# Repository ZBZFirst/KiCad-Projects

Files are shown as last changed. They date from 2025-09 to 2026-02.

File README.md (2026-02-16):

# ESP32 Controller

---

## Reference Images

### PCB Layout

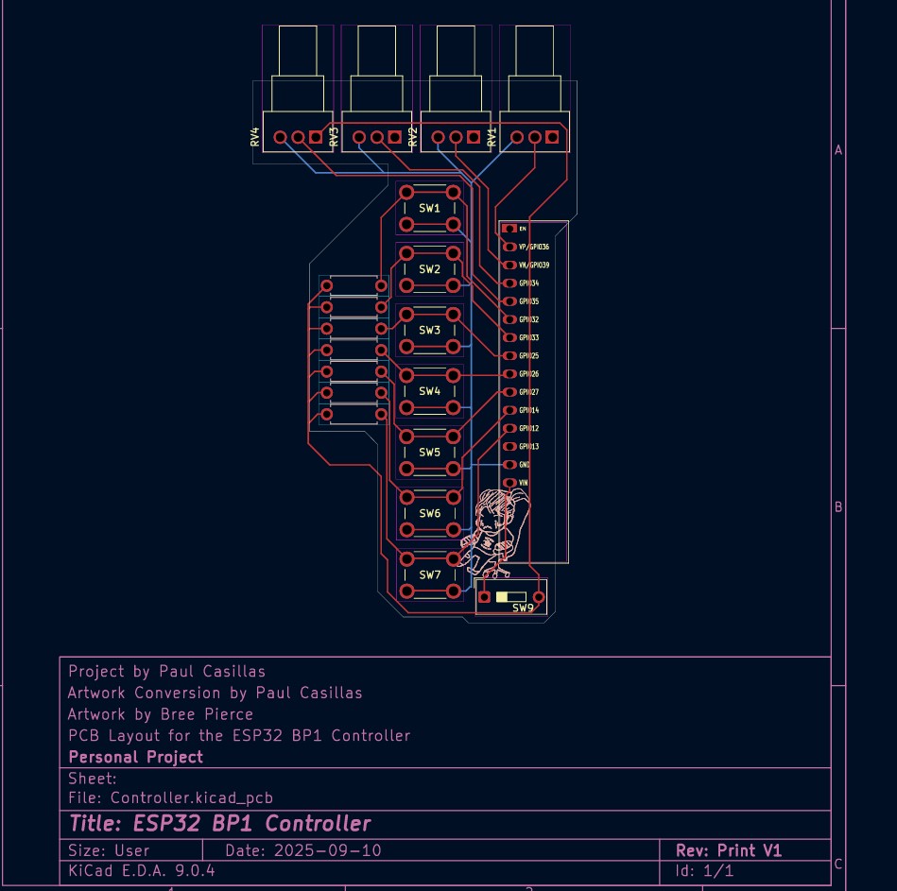
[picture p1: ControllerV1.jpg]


### Attachment

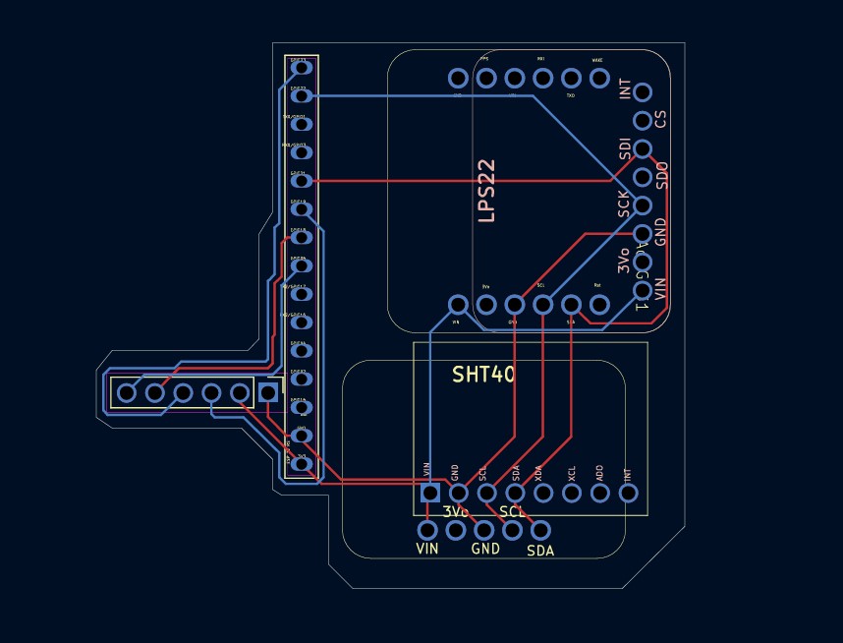
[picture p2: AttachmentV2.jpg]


### Finished Build

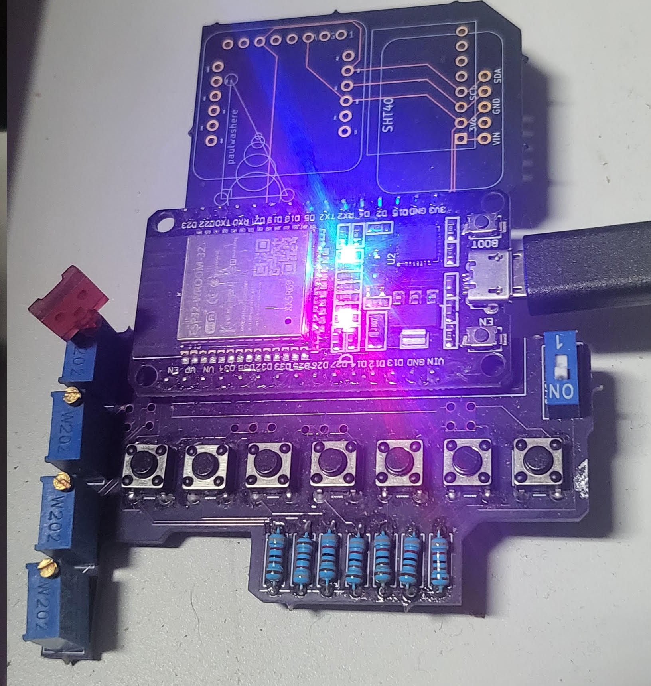
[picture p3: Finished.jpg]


---

Custom ESP32 BLE HID controller + matching PCB design.

This project combines:

- ESP32 firmware (BLE composite keyboard + mouse)
- KiCad PCB layout for a dedicated 7-button controller
- Multi-mode input system for productivity + automation

Designed as a personal hardware controller that behaves like a wireless keyboard/mouse macro pad.

---

## Features

- BLE composite HID device (keyboard + mouse)
- 7 physical buttons
- Mode switching system
- Auto-click / auto-key spam mode
- Windows quick-launch macros
- Non-blocking firmware architecture
- Visual LED status patterns
- Custom PCB layout (KiCad)

---

## Hardware

### Board

ESP32-based custom PCB with:

- 7 tactile switches
- Onboard LED status indicator
- ESP32 dev module header
- Dedicated GPIO routing per button

KiCad layout included in repository.

File:

```
hardware/Controller.kicad_pcb
```

This board is designed specifically to run the included firmware.

---

## Firmware Behavior

The controller has **3 operating groups**.

Button 6 cycles groups.  
Button 7 forces disconnect (reboot).

---

### Group 1 — Default Productivity

| Button | Action |
|---|---|
| B1 | Ctrl + C |
| B2 | Ctrl + V |
| B3 | Ctrl + X |
| B4 | Ctrl + Z |
| B5 | 8-second mouse movement run |

LED: solid ON when connected

---

### Group 2 — Work Launch Macros

| Button | Action |
|---|---|
| B1 | Windows search → cmd → ssh CB37 |
| B2 | Launch Edge |
| B3 | Launch Super |
| B4 | Launch Arduino |
| B5 | Launch Bluetooth |

LED: 2 blink pattern

---

### Group 3 — Auto Mode

Toggle behaviors:

| Button | Mode |
|---|---|
| B1 | Auto left click |
| B2 | Auto right click |
| B3 | Auto middle click |
| B4 | Spam key “E” |
| B5 | Spam key “F” |

Press the same button again to stop.

LED: 3 blink pattern

---

## LED Status

- Off → not connected
- Solid → group 1
- 2 blinks → group 2
- 3 blinks → group 3

Blink sequence repeats every 2 seconds.

---

## Installation

### Requirements

- Arduino IDE
- ESP32 board package
- NimBLE / BLE HID libraries

Open:

```
firmware/PaulsESP32.ino
```

Compile and upload to the board.

---

## Usage

1. Power the controller
2. Pair over Bluetooth
3. Use button 6 to select mode
4. Use buttons 1–5 for actions

Designed primarily for Windows but functions as a generic BLE HID device.

---

## Project Structure

```
firmware/
  PaulsESP32.ino

hardware/
  Controller.kicad_pcb
  schematics/
```

---

## Credits

PCB + firmware design: Paul Casillas  
Artwork: Bree Pierce

Personal project.

---

## License

MIT — free to modify and build.

file is in

AutoClicker/AutoClickerbyController.ino

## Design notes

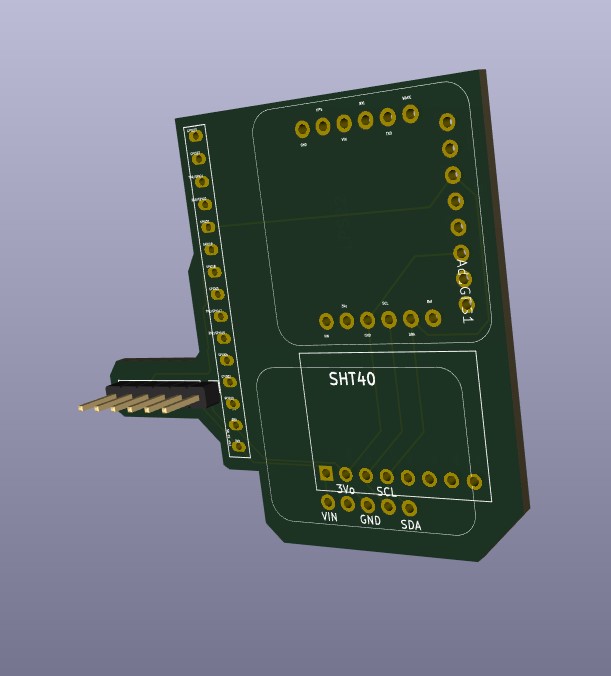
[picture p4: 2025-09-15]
Screenshot 2025-09-10 101046.jpg

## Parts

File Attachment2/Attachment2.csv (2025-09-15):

Reference | Qty | Value | DNP | Exclude from BOM | Exclude from Board | Footprint | Datasheet
AdaGPS1 | 1 | ~ |  |  |  | UserDefined:Adafruit GPS PA1010D
AdaLPS1 | 1 | ~ |  |  |  | UserDefined:LPS22
AdaSHT1 | 1 | ~ |  |  |  | UserDefined:SHTBoard
ESP32RightSide1 | 1 | ESP 32 RS |  |  |  | UserDefined:ESP32-DEVKITV1-Paul-Half2
MPU1 | 1 | 4 Pin Connector |  |  |  | UserDefined:MPU6050HiLetGO | MPU6050
SDCardBoard1 | 1 | SPISDCard |  |  |  | Connector_PinHeader_2.54mm:PinHeader_1x06_P2.54mm_Vertical

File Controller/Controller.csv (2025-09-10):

Reference | Qty | Value | DNP | Exclude from BOM | Exclude from Board | Footprint | Datasheet
NT1 | 1 | NT_Pot1-2+ |  | Excluded from BOM |  | NetTie:NetTie-3_THT_Pad1.0mm | ~
NT2 | 1 | NT_Pot3-4+ |  | Excluded from BOM |  | NetTie:NetTie-3_THT_Pad1.0mm | ~
NT3 | 1 | NT_Pot3-4- |  | Excluded from BOM |  | NetTie:NetTie-3_THT_Pad1.0mm | ~
NT4 | 1 | NT_Pot1-2- |  | Excluded from BOM |  | NetTie:NetTie-3_THT_Pad1.0mm | ~
NT5 | 1 | NT_SW1-2- |  | Excluded from BOM |  | NetTie:NetTie-3_THT_Pad1.0mm | ~
NT6 | 1 | NT_SW3-4- |  | Excluded from BOM |  | NetTie:NetTie-3_THT_Pad1.0mm | ~
NT7 | 1 | NT_SW5-6-7- |  | Excluded from BOM |  | NetTie:NetTie-4_THT_Pad1.0mm | ~
NT8 | 1 | NetTie_3 |  | Excluded from BOM |  | NetTie:NetTie-3_THT_Pad1.0mm | ~
NT9 | 1 | 10K_RS1 |  | Excluded from BOM |  | Resistor_THT:R_Axial_DIN0207_L6.3mm_D2.5mm_P7.62mm_Horizontal | ~
NT10 | 1 | 10K_RS2 |  | Excluded from BOM |  | Resistor_THT:R_Axial_DIN0207_L6.3mm_D2.5mm_P7.62mm_Horizontal | ~
NT11 | 1 | 10K_RS3 |  | Excluded from BOM |  | Resistor_THT:R_Axial_DIN0207_L6.3mm_D2.5mm_P7.62mm_Horizontal | ~
NT12 | 1 | 10K_RS4 |  | Excluded from BOM |  | Resistor_THT:R_Axial_DIN0207_L6.3mm_D2.5mm_P7.62mm_Horizontal | ~
NT13 | 1 | 10K_RS5 |  | Excluded from BOM |  | Resistor_THT:R_Axial_DIN0207_L6.3mm_D2.5mm_P7.62mm_Horizontal | ~
NT14 | 1 | 10K_RS6 |  | Excluded from BOM |  | Resistor_THT:R_Axial_DIN0207_L6.3mm_D2.5mm_P7.62mm_Horizontal | ~
NT15 | 1 | 10K_RS7 |  | Excluded from BOM |  | Resistor_THT:R_Axial_DIN0207_L6.3mm_D2.5mm_P7.62mm_Horizontal | ~
RV1,RV2,RV3,RV4 | 4 | R_Potentiometer_US |  |  |  | Potentiometer_THT:Potentiometer_Alps_RK09Y11_Single_Horizontal | ~
SW1,SW2,SW3,SW4,SW5,SW6,SW7 | 7 | SW_Push |  |  |  | Button_Switch_THT:SW_PUSH_6mm_H5mm | ~
SW9 | 1 | SW_SPST |  |  |  | Button_Switch_THT:SW_DIP_SPSTx01_Slide_9.78x4.72mm_W7.62mm_P2.54mm | ~
U1 | 1 | ~ |  |  |  | Espressif:ESP32-DEVKITV1-Paul-Half

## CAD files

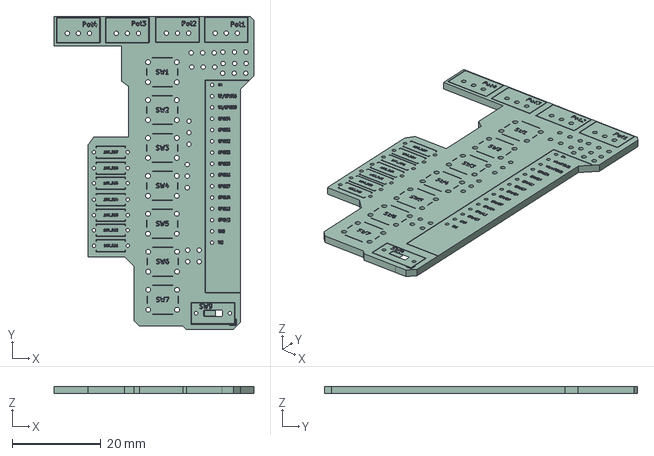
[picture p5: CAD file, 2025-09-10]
Controller/Controller.step
45.0 x 70.6 x 1.66 mm
Controller_silkscreen
Controller_PCB

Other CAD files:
Controller/board.obj

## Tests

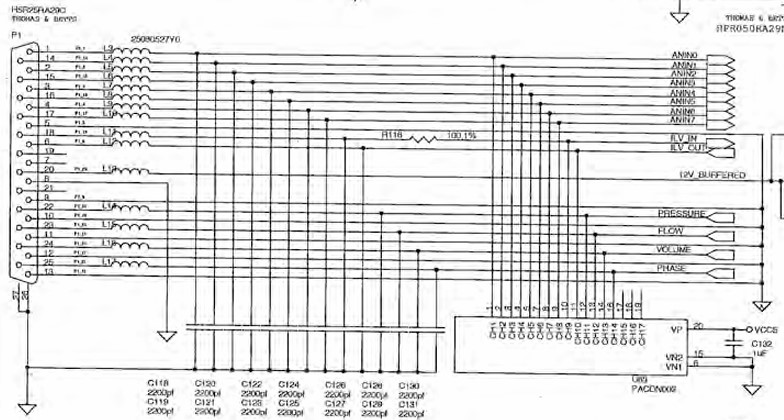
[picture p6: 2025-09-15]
test.jpg

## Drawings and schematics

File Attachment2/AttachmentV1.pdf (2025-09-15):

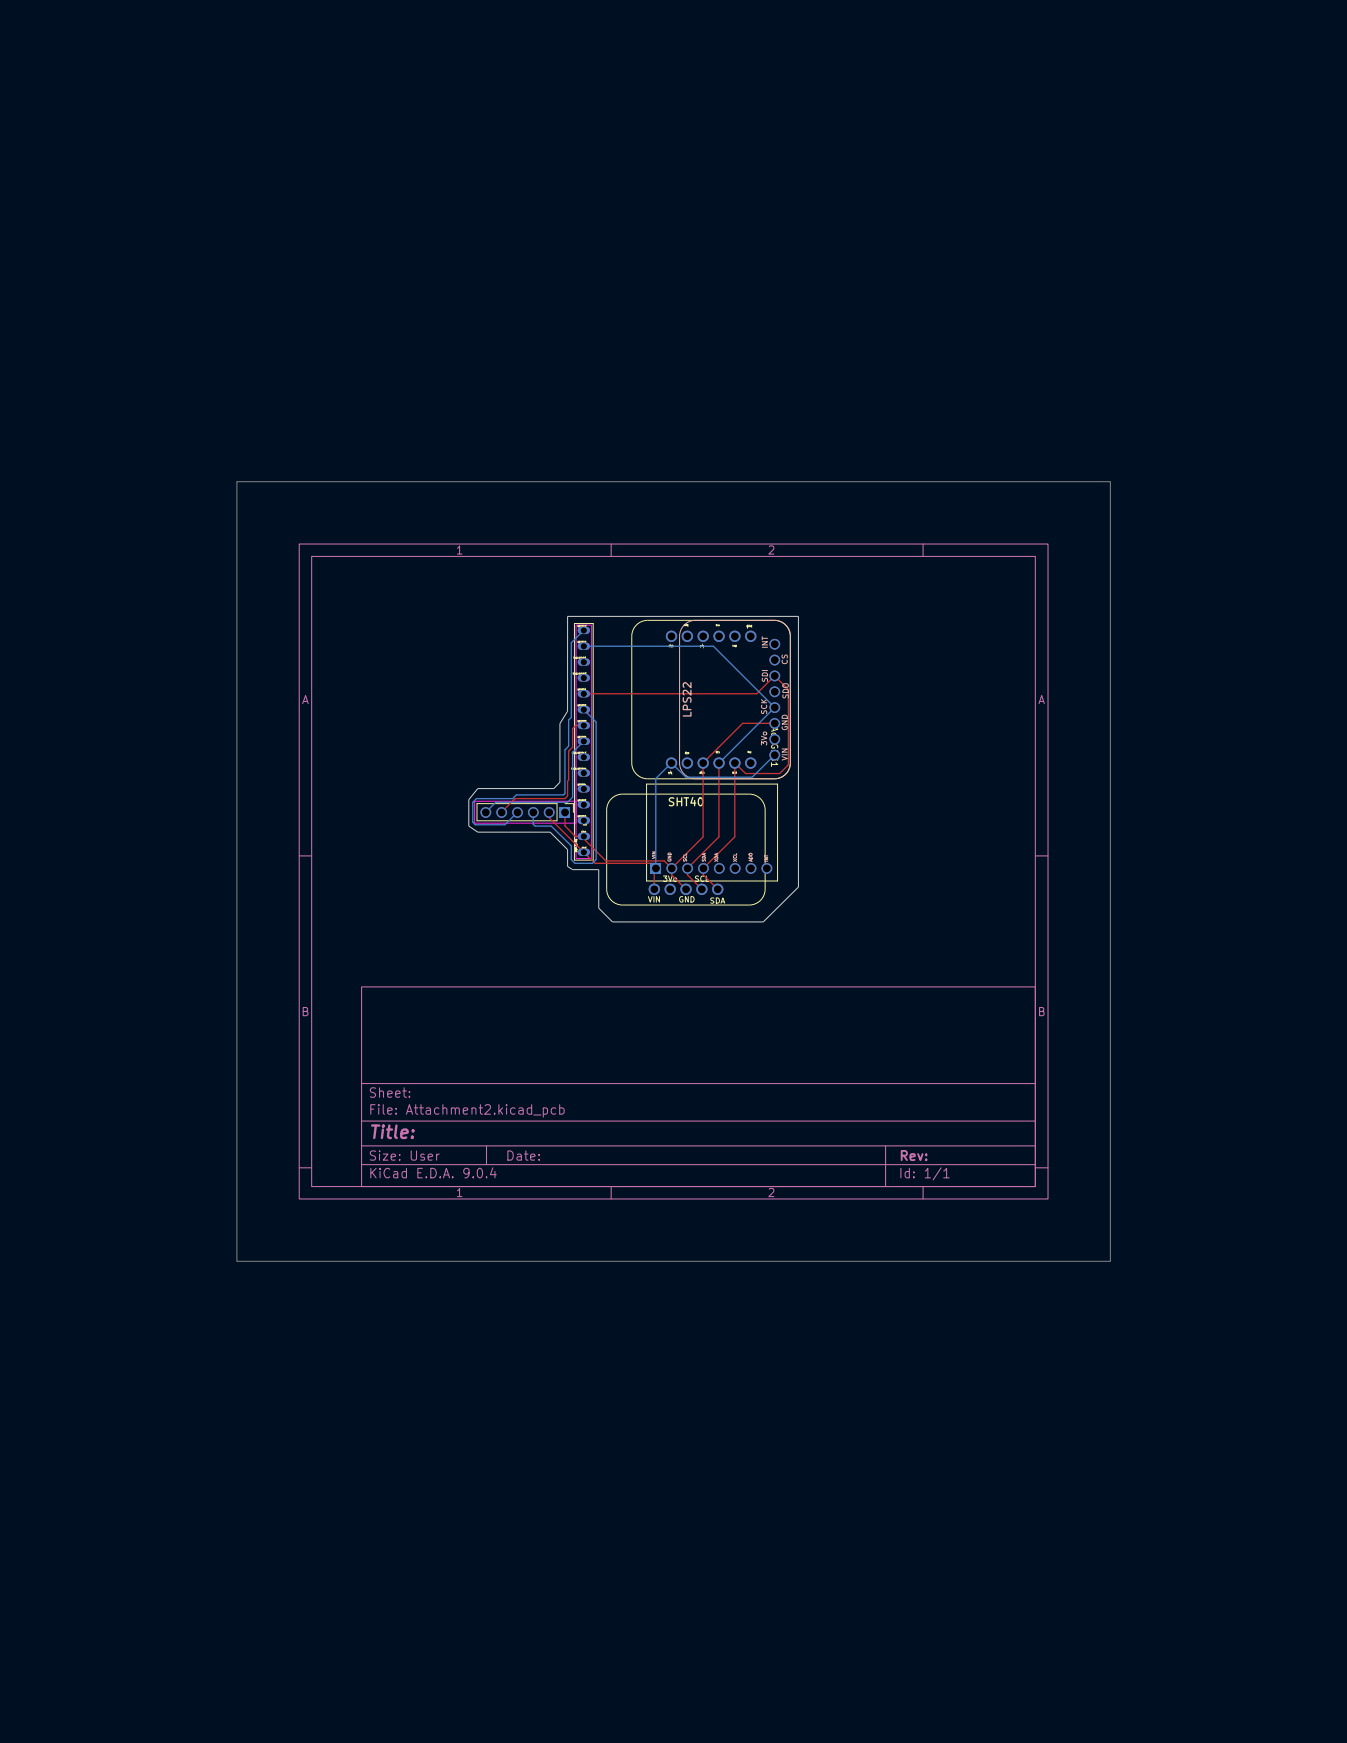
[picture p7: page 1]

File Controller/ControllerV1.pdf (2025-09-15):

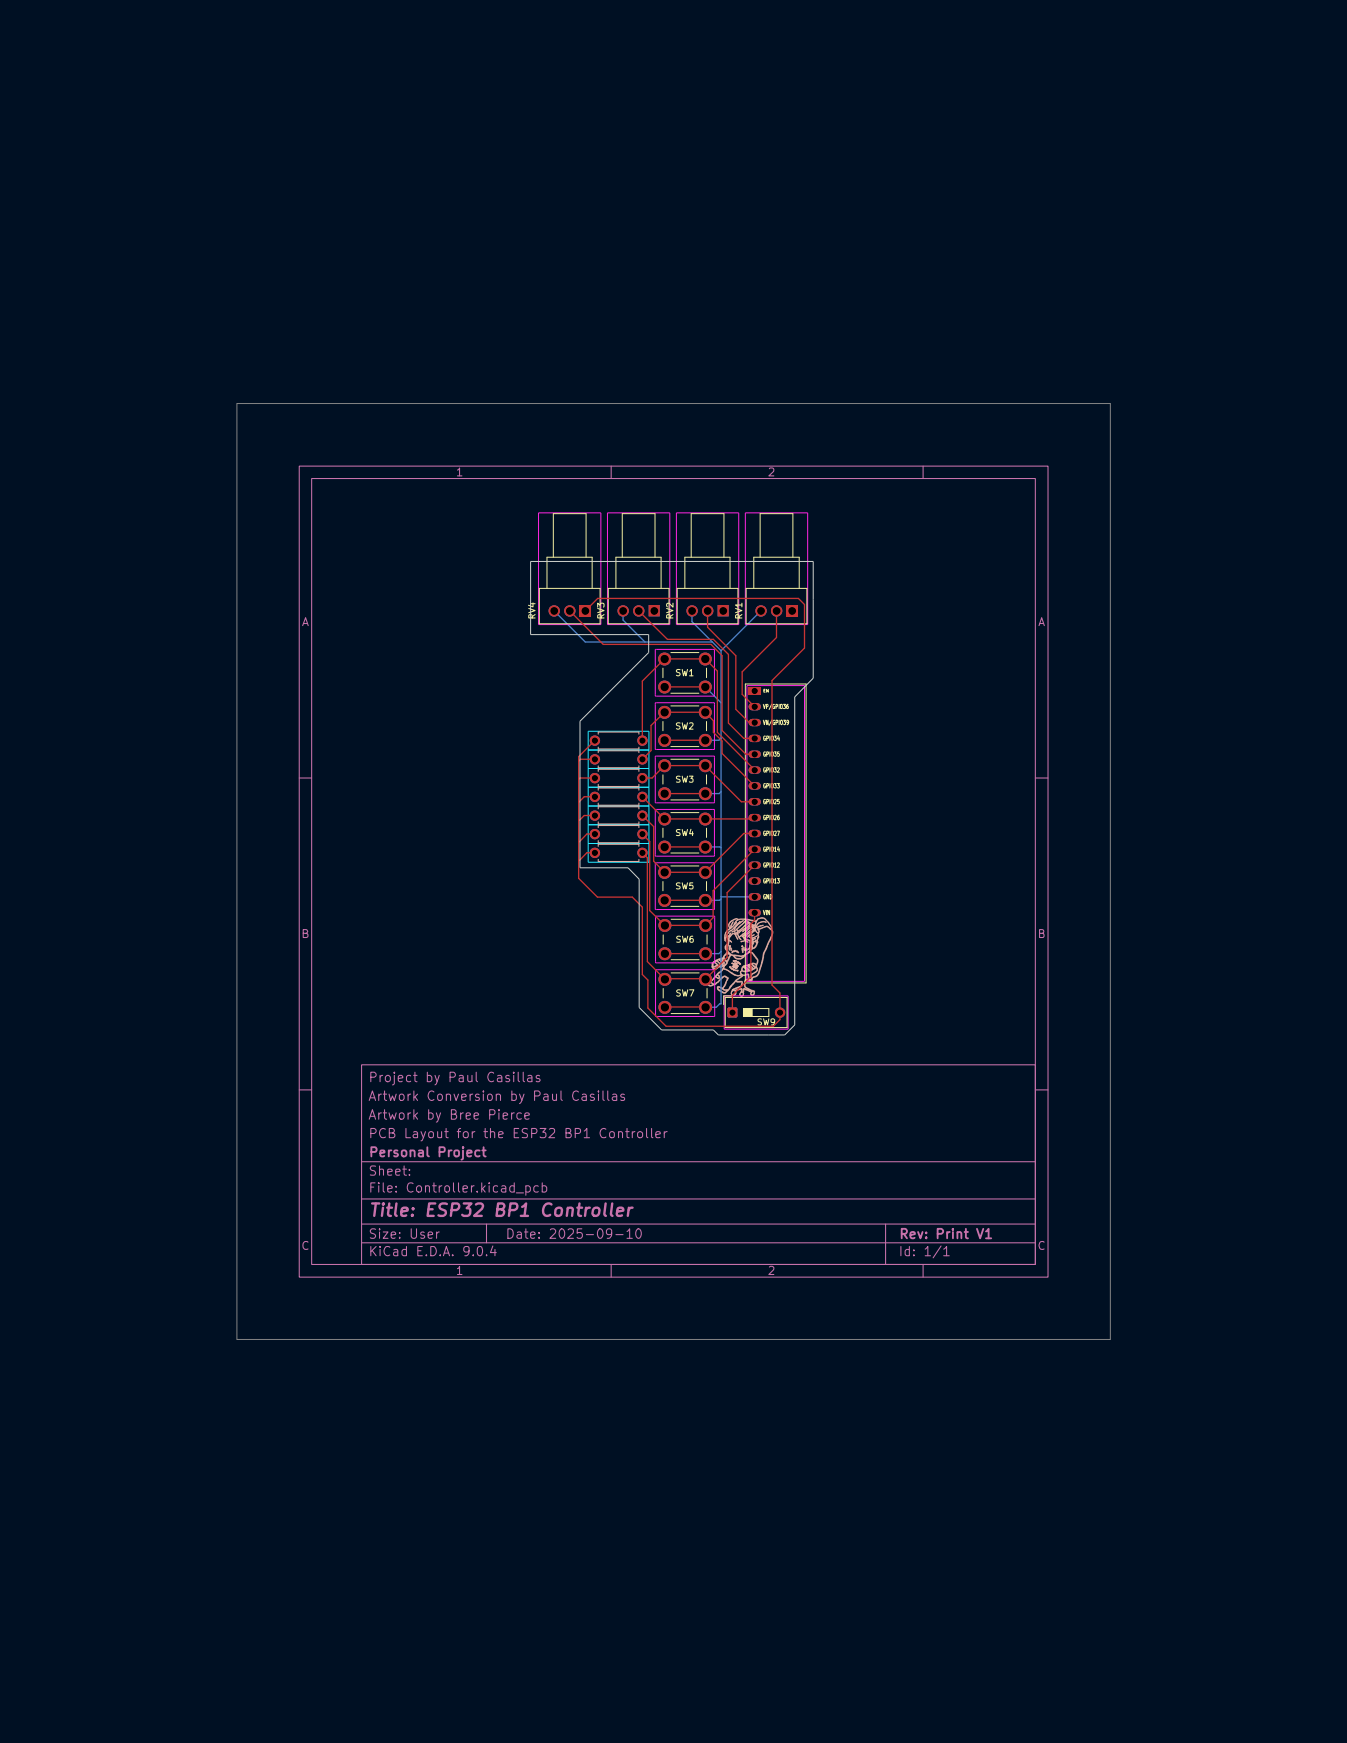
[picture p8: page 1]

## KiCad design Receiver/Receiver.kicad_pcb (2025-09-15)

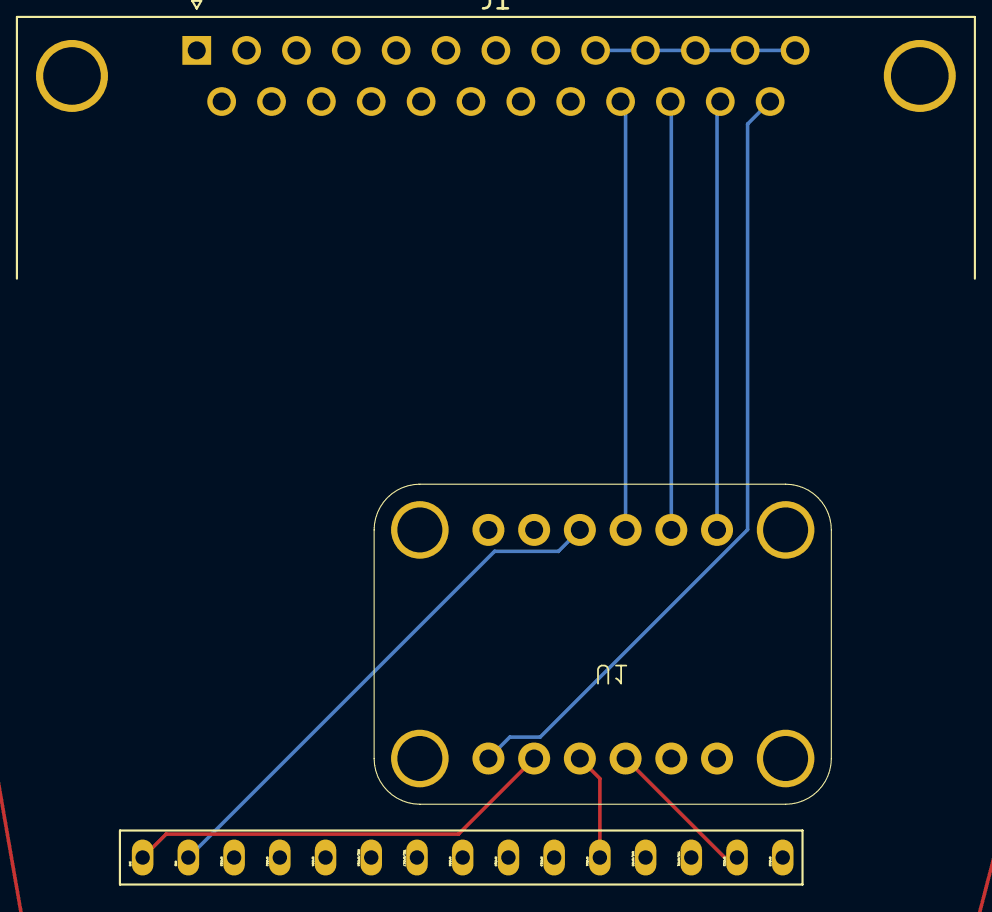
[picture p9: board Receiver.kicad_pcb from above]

Board: 2 copper layers, 3 parts (1 on the bottom side), 9 nets.

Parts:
ESP32 Right Side1: ESP32-DEVKITV1-Paul-Half2
J1: AveaLogic; DSUB-25_Pins_Horizontal_P2.77x2.84mm_EdgePinOffset9.90mm_Ho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
U1: ADS1115IDGS; ADS1115FootPrint

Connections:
GND: J1.9 (GND), J1.10 (GND), J1.11 (GND), J1.12 (GND), J1.13 (GND)
unnamed: ESP32 Right Side1.54 (3V), U1.8 (VDD)
unnamed: ESP32 Right Side1.53 (GND), U1.3 (GND)
unnamed: ESP32 Right Side1.21 (GPIO21/SDA/SDI), U1.9 (SDA)
unnamed: ESP32 Right Side1.22 (GPIO22/SCL/SCK), U1.10 (SCL)
unnamed: J1.23 (FLOW), U1.5 (AIN1)
unnamed: J1.25 (PHASE), U1.7 (AIN3)
unnamed: J1.22 (PRESSURE), U1.4 (AIN0)
unnamed: J1.24 (VOLUME), U1.6 (AIN2)

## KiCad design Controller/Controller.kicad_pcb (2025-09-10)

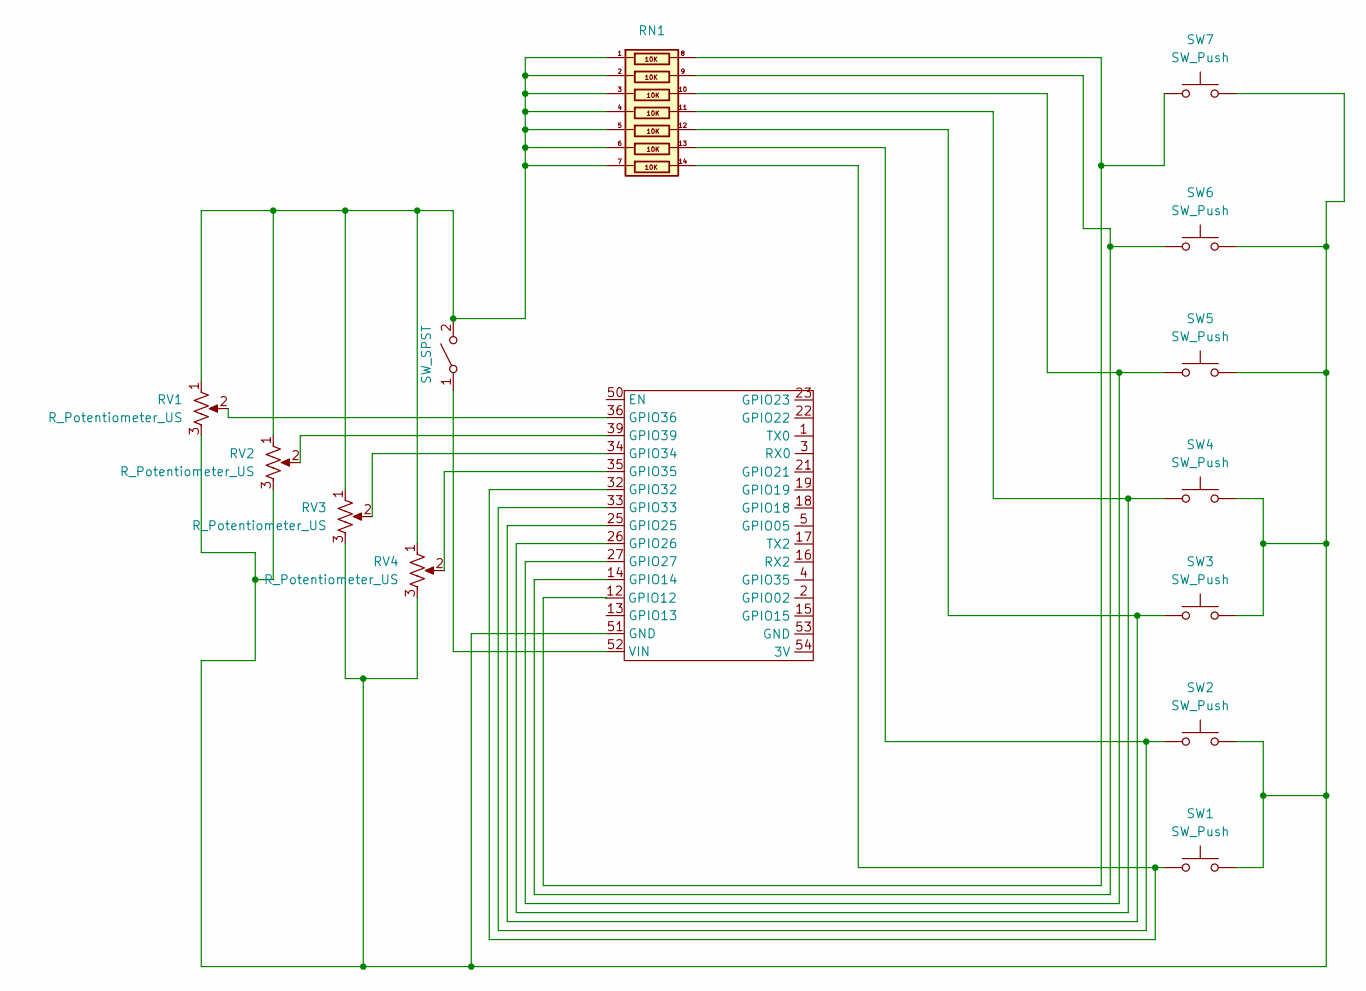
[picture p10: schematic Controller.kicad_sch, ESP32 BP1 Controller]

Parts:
RN1: 10K Array
RV1, RV2, RV3, RV4: R_Potentiometer_US; Potentiometer_Alps_RK09Y11_Single_Horizontal
SW1, SW2, SW3, SW4, SW5, SW6, SW7: SW_Push; SW_PUSH_6mm_H5mm
SW9: SW_SPST; SW_DIP_SPSTx01_Slide_9.78x4.72mm_W7.62mm_P2.54mm
U1: ESP32-DEVKITV1-Paul-Half

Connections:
unnamed: RV1.3, RV2.3, RV3.3, RV4.3, SW1.2, SW2.2, SW3.2, SW4.2, SW5.2, SW6.2, SW7.2, U1.51 (GND)
unnamed: RV4.2, U1.35 (GPIO35)
unnamed: SW9.1 (A), U1.52 (VIN)
unnamed: RN1.1 (R1), RN1.2 (R2), RN1.3 (R3), RN1.4 (R4), RN1.5 (R5), RN1.6 (R6), RN1.7 (R7), RV1.1, RV2.1, RV3.1, RV4.1, SW9.2 (B)
unnamed: RN1.8 (R1), SW7.1, U1.12 (GPIO12)
unnamed: RN1.9 (R2), SW6.1, U1.14 (GPIO14)
unnamed: RN1.12 (R5), SW3.1, U1.25 (GPIO25)
unnamed: RN1.11 (R4), SW4.1, U1.26 (GPIO26)
unnamed: RN1.10 (R3), SW5.1, U1.27 (GPIO27)
unnamed: RN1.14 (R7), SW1.1, U1.32 (GPIO32)
unnamed: RN1.13 (R6), SW2.1, U1.33 (GPIO33)
unnamed: RV3.2, U1.34 (GPIO34)
unnamed: RV1.2, U1.36 (GPIO36)
unnamed: RV2.2, U1.39 (GPIO39)

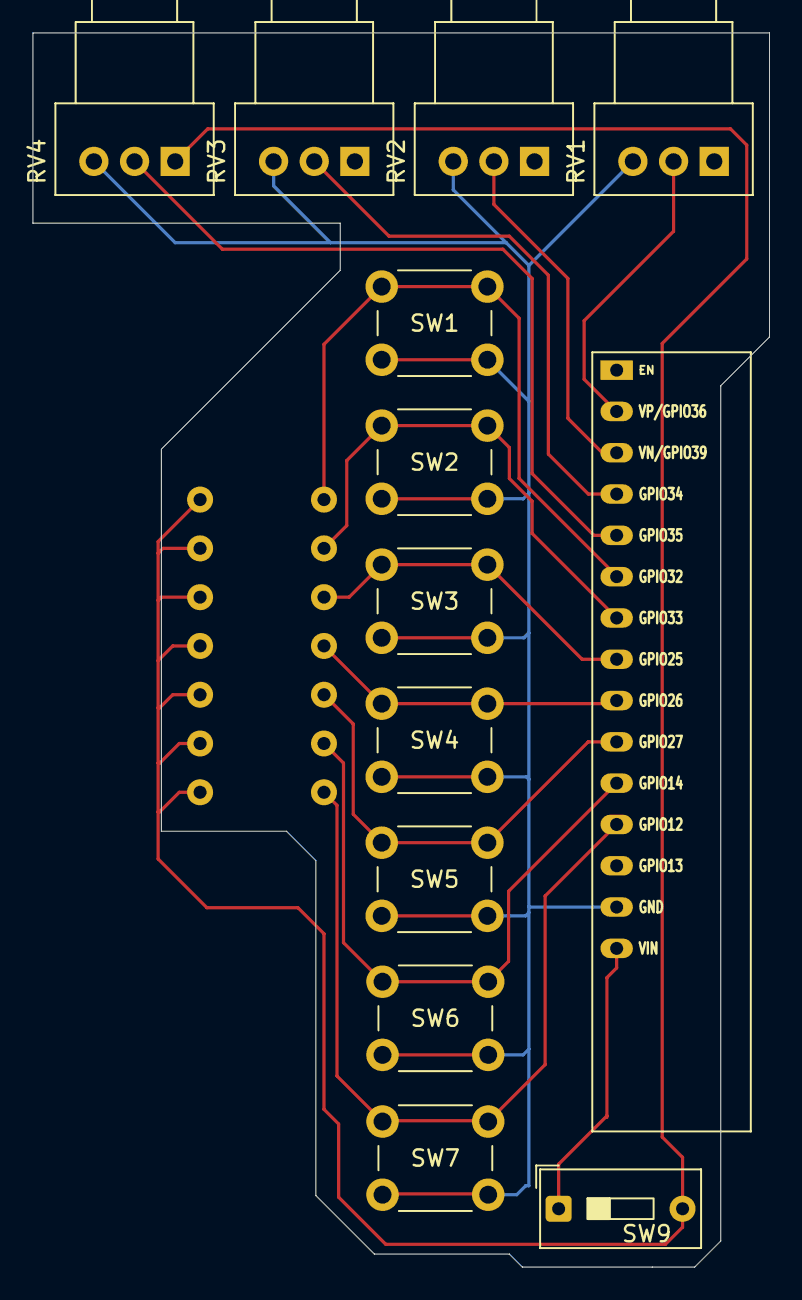
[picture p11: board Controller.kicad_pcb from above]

Board: 2 copper layers, 45.3 x 75.9 mm, 14 parts (1 on the bottom side), 14 nets.

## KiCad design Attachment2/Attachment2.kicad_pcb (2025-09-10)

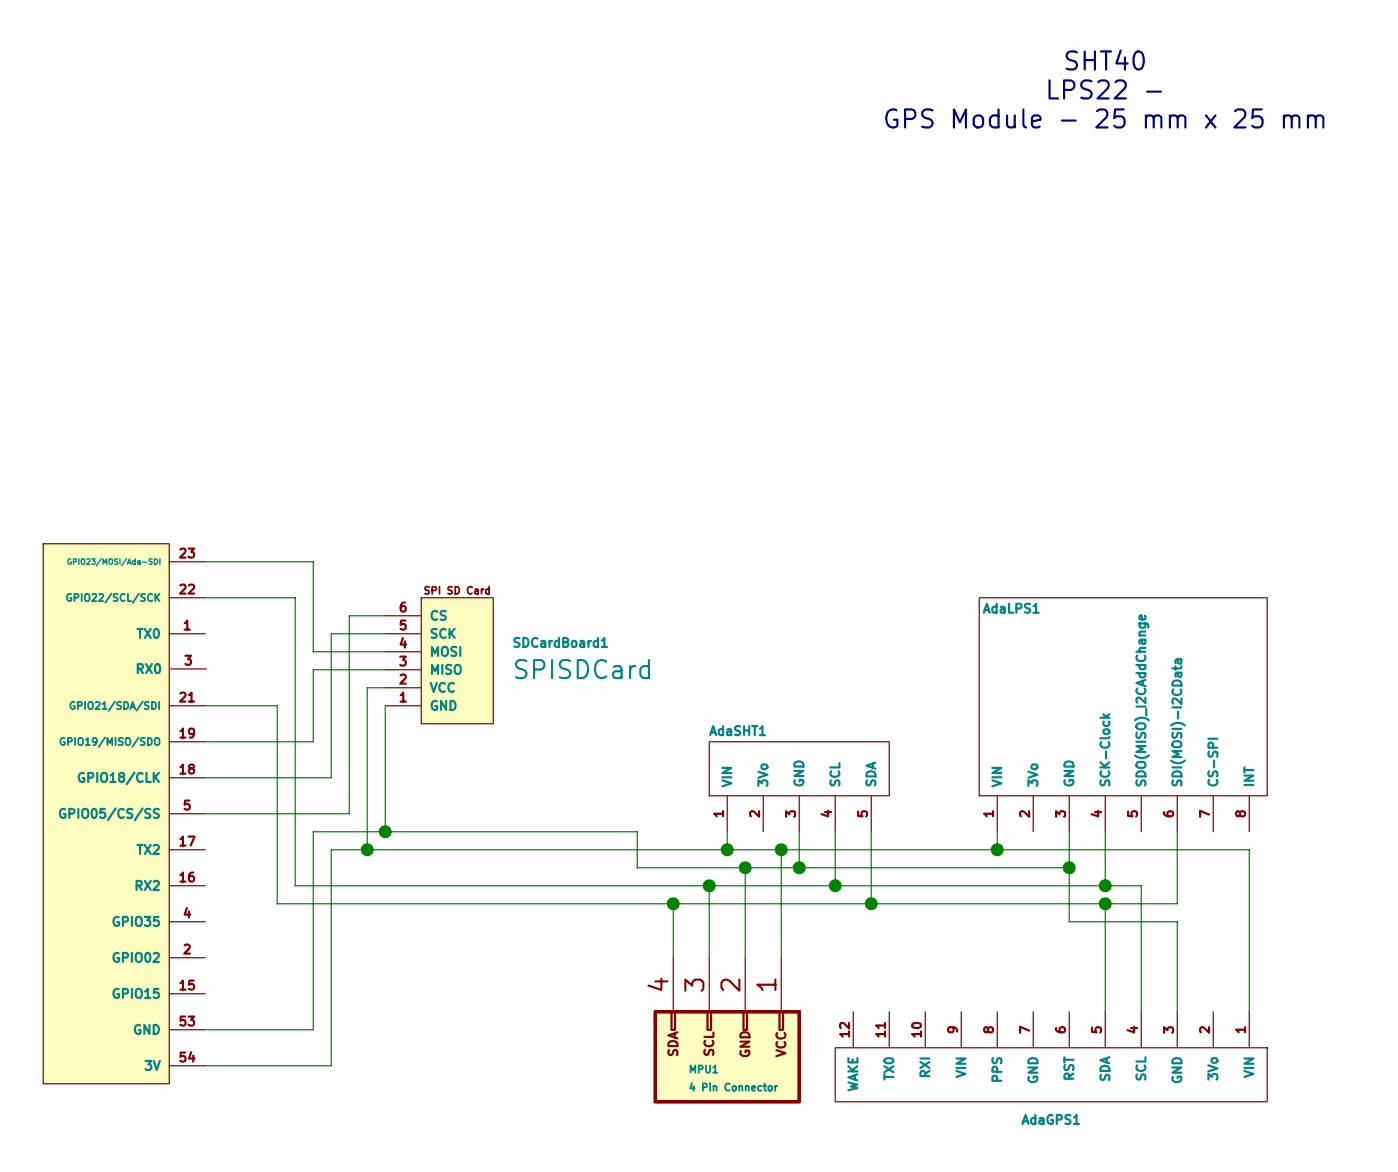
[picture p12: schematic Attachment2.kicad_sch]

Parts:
AdaGPS1: Adafruit GPS PA1010D
AdaLPS1: LPS22
AdaSHT1: SHTBoard
ESP32RightSide1: ESP 32 RS; ESP32-DEVKITV1-Paul-Half2
MPU1: 4 Pin Connector; MPU6050HiLetGO
SDCardBoard1: SPISDCard; PinHeader_1x06_P2.54mm_Vertical

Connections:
unnamed: AdaGPS1.4 (SCL), AdaLPS1.4 (SCK-Clock), AdaSHT1.4 (SCL), ESP32RightSide1.22 (GPIO22/SCL/SCK), MPU1.3 (SCL)
unnamed: AdaGPS1.5 (SDA), AdaLPS1.6 (SDI(MOSI)-I2CData), AdaSHT1.5 (SDA), ESP32RightSide1.21 (GPIO21/SDA/SDI), MPU1.4 (SDA)
unnamed: AdaGPS1.3 (GND), AdaLPS1.3 (GND), AdaSHT1.3 (GND), ESP32RightSide1.53 (GND), MPU1.2 (GND), SDCardBoard1.1 (GND)
unnamed: AdaGPS1.1 (VIN), AdaLPS1.1 (VIN), AdaSHT1.1 (VIN), ESP32RightSide1.54 (3V), MPU1.1 (VCC), SDCardBoard1.2 (VCC)
unnamed: ESP32RightSide1.5 (GPIO05/CS/SS), SDCardBoard1.6 (CS)
unnamed: ESP32RightSide1.18 (GPIO18/CLK), SDCardBoard1.5 (SCK)
unnamed: ESP32RightSide1.19 (GPIO19/MISO/SDO), SDCardBoard1.3 (MISO)
unnamed: ESP32RightSide1.23 (GPIO23/MOSI/Ada-SDI), SDCardBoard1.4 (MOSI)

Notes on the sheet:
SHT40 LPS22 - GPS Module - 25 mm x 25 mm

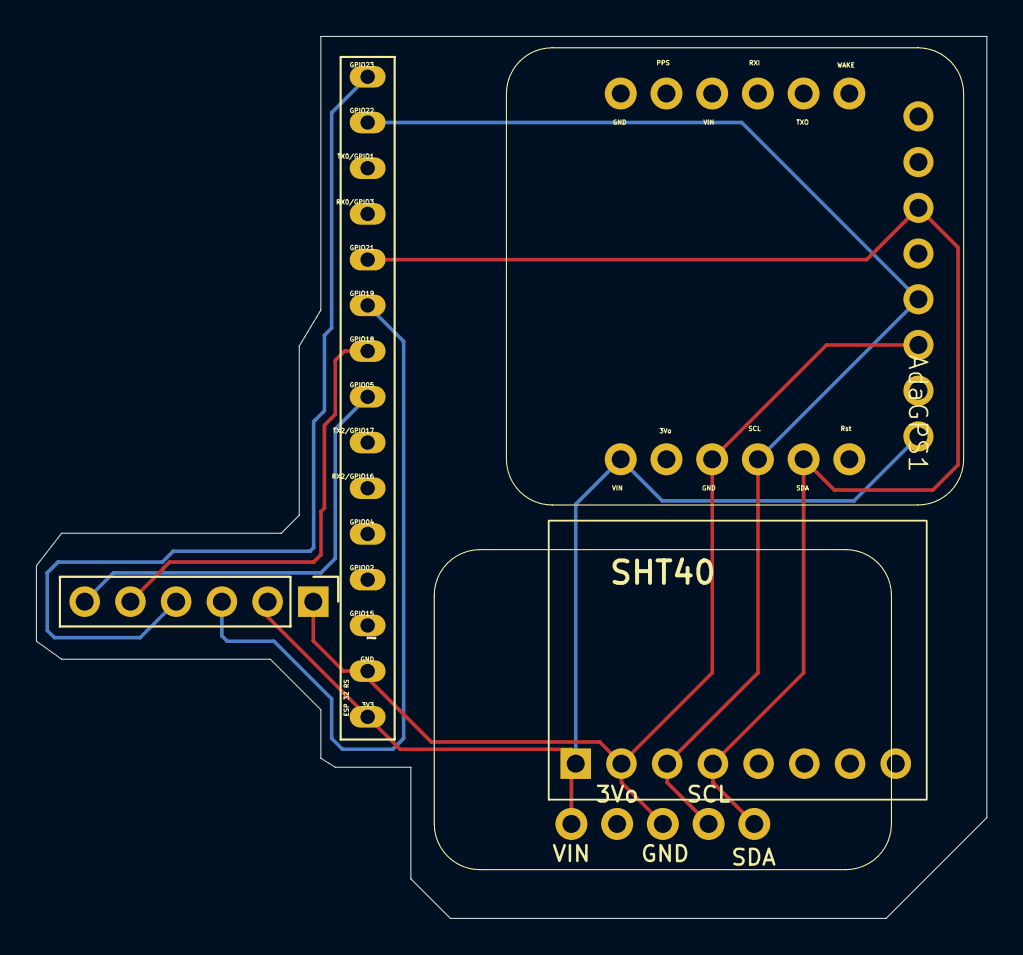
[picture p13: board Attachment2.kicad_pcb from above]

Board: 2 copper layers, 52.8 x 49.0 mm, 6 parts (0 on the bottom side), 8 nets.

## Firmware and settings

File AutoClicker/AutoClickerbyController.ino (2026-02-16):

#include <Arduino.h>
#include <math.h>

#include <BleConnectionStatus.h>
#include <BleCompositeHID.h>
#include <KeyboardDevice.h>
#include <MouseDevice.h>

// ============================
// BLE device identity (edit)
// ============================
#define BLE_DEVICE_NAME   "PaulsESP32"
#define BLE_MANUFACTURER  "PaulLab"

// ============================
// Pull configuration (flip ONE value)
// ============================
#define USE_PULLUP 1   // 1 = INPUT_PULLUP, 0 = INPUT_PULLDOWN

#if USE_PULLUP
  const uint8_t BUTTON_PULL_MODE = INPUT_PULLUP;
  const uint8_t PRESSED_LEVEL    = LOW;
#else
  const uint8_t BUTTON_PULL_MODE = INPUT_PULLDOWN;
  const uint8_t PRESSED_LEVEL    = HIGH;
#endif

// ============================
// 7-button generic index mapping
// ============================
static const int BTN_COUNT = 7;

uint8_t btnPin[BTN_COUNT] = {
  32, // Button 1
  33, // Button 2
  25, // Button 3
  26, // Button 4
  27, // Button 5
  14, // Button 6 (Group switch)
  12  // Button 7 (Disconnect / reboot)
};

// ============================
// Onboard LED (board-specific)
// ============================
#ifndef LED_BUILTIN
  #define LED_BUILTIN 2  // common on many ESP32 dev boards
#endif

static const bool LED_ACTIVE_LOW = false; // set true if your LED behaves inverted

static inline void setLed(bool on) {
  bool levelHigh = (LED_ACTIVE_LOW ? !on : on);
  digitalWrite(LED_BUILTIN, levelHigh ? HIGH : LOW);
}

// ============================
// Timing knobs
// ============================
static const uint32_t DEBOUNCE_MS   = 35;
static const uint32_t MOUSE_RUN_MS  = 8000;   // one run duration
static const uint32_t MOUSE_TICK_MS = 16;     // ~60Hz

// LED pattern requirements
static const uint32_t LED_BLINK_MS = 100;   // 100ms ON, 100ms OFF
static const uint32_t LED_PAUSE_MS = 2000;  // 2s between sequences

// ============================
// HID devices
// ============================
KeyboardDevice* keyboard;
MouseDevice* mouse;
BleCompositeHID compositeHID(BLE_DEVICE_NAME, BLE_MANUFACTURER, 100);

// IMPORTANT: match the working example (advertise as keyboard)
BLEHostConfiguration bleHostConfig;

// ============================
// Button debounce state
// ============================
uint8_t  btnStable[BTN_COUNT]       = {0};
uint8_t  btnLastRead[BTN_COUNT]     = {0};
uint32_t btnLastChangeMs[BTN_COUNT] = {0};

// ============================
// Mouse run state (non-blocking)
// ============================
bool     mouseRunActive   = false;
uint32_t mouseRunStartMs  = 0;
uint32_t mouseLastTickMs  = 0;

// ============================
// Group / mode state
// ============================
static const uint8_t GROUP_DEFAULT = 1;
static const uint8_t GROUP_WORK    = 2;
static const uint8_t GROUP_AUTO    = 3; // was PHRASES

uint8_t actionGroup = GROUP_DEFAULT;

// ============================
// Group 3: Auto-click / auto-key state
// ============================
static const uint8_t AUTO_OFF    = 0;
static const uint8_t AUTO_LCLICK = 1;
static const uint8_t AUTO_RCLICK = 2;
static const uint8_t AUTO_MCLICK = 3;
static const uint8_t AUTO_KEY_E  = 4;
static const uint8_t AUTO_KEY_F  = 5;

uint8_t  autoMode       = AUTO_OFF;
uint32_t autoLastTickMs = 0;

// speed of the auto click / key spam
static const uint32_t AUTO_TICK_MS = 50; // 50ms = 20 actions/sec

// ============================
// LED pattern state machine
// ============================
enum LedPhase : uint8_t { LED_STEADY = 0, LED_ON_PULSE = 1, LED_OFF_PULSE = 2, LED_PAUSE = 3 };

LedPhase ledPhase = LED_STEADY;
uint8_t  ledTargetBlinks = 0;  // 0 => steady mode
uint8_t  ledBlinksDone   = 0;
uint32_t ledPhaseStartMs = 0;

static void resetLedPattern() {
  ledPhase = LED_STEADY;
  ledTargetBlinks = 0;
  ledBlinksDone = 0;
  ledPhaseStartMs = 0;
}

static uint8_t desiredBlinksForGroup(uint8_t group) {
  if (group == GROUP_WORK) return 2;
  if (group == GROUP_AUTO) return 3;
  return 0; // default group = steady ON
}

static void tickLed() {
  bool connected = compositeHID.isConnected();
  uint32_t now = millis();

  // Rule: if not connected, LED OFF.
  if (!connected) {
    setLed(false);
    resetLedPattern();
    return;
  }

  // Connected: decide target pattern from group
  uint8_t desired = desiredBlinksForGroup(actionGroup);

  // If group changed (or we were reset), re-init LED state
  if (desired != ledTargetBlinks && ledTargetBlinks != 0) {
    // (Handled on group-change too, but this makes it robust)
    resetLedPattern();
  }
  ledTargetBlinks = desired;

  // Group 1: steady ON
  if (ledTargetBlinks == 0) {
    setLed(true);
    ledPhase = LED_STEADY;
    return;
  }

  // Groups 2/3: blink N times, then pause 2s, repeat.
  // During pause, LED stays ON (connected indicator), with brief blink interruptions.
  if (ledPhase == LED_STEADY) {
    ledPhase = LED_ON_PULSE;
    ledBlinksDone = 0;
    ledPhaseStartMs = now;
    setLed(true);
    return;
  }

  if (ledPhase == LED_ON_PULSE) {
    if ((now - ledPhaseStartMs) >= LED_BLINK_MS) {
      ledPhase = LED_OFF_PULSE;
      ledPhaseStartMs = now;
      setLed(false);
    }
    return;
  }

  if (ledPhase == LED_OFF_PULSE) {
    if ((now - ledPhaseStartMs) >= LED_BLINK_MS) {
      ledBlinksDone++;

      if (ledBlinksDone >= ledTargetBlinks) {
        ledPhase = LED_PAUSE;
        ledPhaseStartMs = now;
        setLed(true); // ON during the 2s delay
      } else {
        ledPhase = LED_ON_PULSE;
        ledPhaseStartMs = now;
        setLed(true);
      }
    }
    return;
  }

  // LED_PAUSE
  if ((now - ledPhaseStartMs) >= LED_PAUSE_MS) {
    ledPhase = LED_ON_PULSE;
    ledBlinksDone = 0;
    ledPhaseStartMs = now;
    setLed(true);
  }
}

// ---------- helpers ----------
static inline bool rawPressed(int idx) {
  return digitalRead(btnPin[idx]) == PRESSED_LEVEL;
}

// debounced press edge: true exactly once per press
bool pressedEdge(int idx) {
  uint32_t now = millis();
  uint8_t raw = rawPressed(idx) ? 1 : 0;

  if (raw != btnLastRead[idx]) {
    btnLastRead[idx] = raw;
    btnLastChangeMs[idx] = now;
  }

  if ((now - btnLastChangeMs[idx]) >= DEBOUNCE_MS) {
    if (btnStable[idx] != raw) {
      btnStable[idx] = raw;
      if (btnStable[idx] == 1) return true;
    }
  }
  return false;
}

// Send Ctrl + <key> using modifier-mask path.
void sendCtrlChord(uint8_t keyCode) {
  if (!compositeHID.isConnected()) return;

  keyboard->resetKeys();

  keyboard->modifierKeyPress(KEY_MOD_LCTRL);
  keyboard->keyPress(keyCode);
  delay(10);
  keyboard->keyRelease(keyCode);
  keyboard->modifierKeyRelease(KEY_MOD_LCTRL);

  keyboard->resetKeys();
}

// ============================
// Mouse run (non-blocking circle move)
// ============================
void startMouseRunOnce() {
  mouseRunActive  = true;
  mouseRunStartMs = millis();
  mouseLastTickMs = 0;
  Serial.println("Mouse run: START");
}

void tickMouseRun() {
  if (!mouseRunActive) return;
  if (!compositeHID.isConnected()) return;

  uint32_t now = millis();

  if (now - mouseRunStartMs >= MOUSE_RUN_MS) {
    mouseRunActive = false;
    Serial.println("Mouse run: DONE");
    return;
  }

  if (mouseLastTickMs != 0 && (now - mouseLastTickMs) < MOUSE_TICK_MS) return;
  mouseLastTickMs = now;

  int8_t x = (int8_t)lroundf(cosf((float)now / 1000.0f) * 10.0f);
  int8_t y = (int8_t)lroundf(sinf((float)now / 1000.0f) * 10.0f);

  mouse->mouseMove(x, y);
  mouse->sendMouseReport();
}

// With AutoReport(false), we MUST send reports manually.
static void doMouseClickLogical(uint8_t logicalButton) {
  mouse->mousePress(logicalButton);
  mouse->sendMouseReport();
  delay(3);
  mouse->mouseRelease(logicalButton);
  mouse->sendMouseReport();
}

// ============================
// Typing helpers (ASCII -> HID)
// ============================
static inline void tapKey(uint8_t keyCode, uint16_t msDown = 8) {
  keyboard->keyPress(keyCode);
  delay(msDown);
  keyboard->keyRelease(keyCode);
  delay(4);
}

static inline void tapEnter() {
  tapKey(KEY_ENTER);
}

static inline void tapWin() {
  // META = Windows/GUI key in your keymap
  keyboard->modifierKeyPress(KEY_MOD_LMETA);
  delay(8);
  keyboard->modifierKeyRelease(KEY_MOD_LMETA);
  delay(60); // allow Windows search UI to appear
}

// Supports: letters (a-z/A-Z), digits (0-9), space.
static bool asciiToHid(char c, uint8_t &keyCode, bool &needsShift) {
  needsShift = false;

  if (c >= 'a' && c <= 'z') {
    keyCode = (uint8_t)(KEY_A + (c - 'a'));
    return true;
  }

  if (c >= 'A' && c <= 'Z') {
    keyCode = (uint8_t)(KEY_A + (c - 'A'));
    needsShift = true;
    return true;
  }

  if (c >= '1' && c <= '9') {
    keyCode = (uint8_t)(KEY_1 + (c - '1'));
    return true;
  }
  if (c == '0') {
    keyCode = KEY_0;
    return true;
  }

  if (c == ' ') {
    keyCode = KEY_SPACE;
    return true;
  }

  return false;
}

static void typeChar(char c) {
  uint8_t keyCode = 0;
  bool shift = false;

  if (!asciiToHid(c, keyCode, shift)) return;

  if (shift) keyboard->modifierKeyPress(KEY_MOD_LSHIFT);
  tapKey(keyCode, 6);
  if (shift) keyboard->modifierKeyRelease(KEY_MOD_LSHIFT);
}

static void typeText(const char* s) {
  if (!compositeHID.isConnected()) return;

  keyboard->resetKeys();
  for (const char* p = s; *p; ++p) {
    typeChar(*p);
    delay(6);
  }
  keyboard->resetKeys();
}

static void winSearchAndEnter(const char* query) {
  if (!compositeHID.isConnected()) return;

  tapWin();
  typeText(query);
  tapEnter();
}

static void work_btn1_cmd_ssh() {
  winSearchAndEnter("cmd");
  delay(180);
  typeText("ssh CB37");
  tapEnter();
}

// ============================
// AUTO mode helpers
// ============================
static void stopAutoMode() {
  autoMode = AUTO_OFF;
  autoLastTickMs = 0;
}

static void toggleAutoMode(uint8_t desiredMode) {
  if (autoMode == desiredMode) {
    stopAutoMode();
    Serial.println("AUTO: OFF");
  } else {
    autoMode = desiredMode;
    autoLastTickMs = 0;

    Serial.print("AUTO: ");
    switch (autoMode) {
      case AUTO_LCLICK: Serial.println("LEFT CLICK"); break;
      case AUTO_RCLICK: Serial.println("RIGHT CLICK"); break;
      case AUTO_MCLICK: Serial.println("MIDDLE CLICK"); break;
      case AUTO_KEY_E:  Serial.println("KEY 'e'"); break;
      case AUTO_KEY_F:  Serial.println("KEY 'f'"); break;
      default:          Serial.println("UNKNOWN"); break;
    }
  }
}

static void tickAutoMode() {
  if (autoMode == AUTO_OFF) return;
  if (!compositeHID.isConnected()) return;

  uint32_t now = millis();
  if (autoLastTickMs != 0 && (now - autoLastTickMs) < AUTO_TICK_MS) return;
  autoLastTickMs = now;

  if (autoMode == AUTO_LCLICK) {
    doMouseClickLogical(MOUSE_LOGICAL_LEFT_BUTTON);
  } else if (autoMode == AUTO_RCLICK) {
    doMouseClickLogical(MOUSE_LOGICAL_RIGHT_BUTTON);
  } else if (autoMode == AUTO_MCLICK) {
    doMouseClickLogical(MOUSE_LOGICAL_BUTTON_3);
  } else if (autoMode == AUTO_KEY_E) {
    tapKey(KEY_E, 4);
  } else if (autoMode == AUTO_KEY_F) {
    tapKey(KEY_F, 4);
  }
}

// ============================
// Setup / loop
// ============================
void setup() {
  Serial.begin(115200);
  delay(200);

  // LED
  pinMode(LED_BUILTIN, OUTPUT);
  setLed(false);

  // Buttons
  for (int i = 0; i < BTN_COUNT; i++) {
    pinMode(btnPin[i], BUTTON_PULL_MODE);
    btnLastRead[i] = rawPressed(i) ? 1 : 0;
    btnStable[i] = btnLastRead[i];
    btnLastChangeMs[i] = millis();
  }

  // Advertise as keyboard (matches your working sketch)
  bleHostConfig.setHidType(HID_KEYBOARD);

  // Keyboard: auto reports on press/release
  KeyboardConfiguration keyboardConfig;
  keyboardConfig.setAutoReport(true);
  keyboard = new KeyboardDevice(keyboardConfig);

  // Mouse: manual, since we send at our own tick rate
  MouseConfiguration mouseConfig;
  mouseConfig.setAutoReport(false);
  mouse = new MouseDevice(mouseConfig);

  // Composite HID
  compositeHID.addDevice(keyboard);
  compositeHID.addDevice(mouse);
  compositeHID.begin(bleHostConfig);

  Serial.println("Composite HID started.");
  Serial.println("Group -> DEFAULT");
}

void loop() {
  // Always tick background actions (non-blocking)
  tickMouseRun();
  tickAutoMode();
  tickLed();

  // Button 7: disconnect (reboot drops link; host may auto-reconnect)
  if (pressedEdge(6)) {
    Serial.println("Button 7: disconnect -> reboot");
    delay(100);
    ESP.restart();
  }

  // Button 6: cycle group (works even when not connected)
  if (pressedEdge(5)) {
    actionGroup++;
    if (actionGroup > GROUP_AUTO) actionGroup = GROUP_DEFAULT;

    // Switching groups should stop AUTO spam
    stopAutoMode();

    // Reset LED pattern timing immediately on group change
    resetLedPattern();

    Serial.print("Group -> ");
    if (actionGroup == GROUP_DEFAULT) Serial.println("DEFAULT");
    else if (actionGroup == GROUP_WORK) Serial.println("WORK");
    else Serial.println("AUTO");
  }

  // Nothing else should run unless connected
  if (!compositeHID.isConnected()) return;

  // Buttons 1-5: dispatch by group
  if (actionGroup == GROUP_DEFAULT) {
    if (pressedEdge(0)) { sendCtrlChord(KEY_C); Serial.println("B1: Ctrl+C"); }
    if (pressedEdge(1)) { sendCtrlChord(KEY_V); Serial.println("B2: Ctrl+V"); }
    if (pressedEdge(2)) { sendCtrlChord(KEY_X); Serial.println("B3: Ctrl+X"); }
    if (pressedEdge(3)) { sendCtrlChord(KEY_Z); Serial.println("B4: Ctrl+Z"); }
    if (pressedEdge(4)) { if (!mouseRunActive) startMouseRunOnce(); Serial.println("B5: Mouse run"); }
  }
  else if (actionGroup == GROUP_WORK) {
    if (pressedEdge(0)) { work_btn1_cmd_ssh();       Serial.println("B1: Win cmd -> ssh CB37"); }
    if (pressedEdge(1)) { winSearchAndEnter("edge"); Serial.println("B2: Win edge"); }
    if (pressedEdge(2)) { winSearchAndEnter("super");Serial.println("B3: Win super"); }
    if (pressedEdge(3)) { winSearchAndEnter("ard");  Serial.println("B4: Win ard"); }
    if (pressedEdge(4)) { winSearchAndEnter("blue"); Serial.println("B5: Win blue"); }
  }
  else { // GROUP_AUTO
    // Toggle behaviors:
    // B1 left click, B2 right click, B3 middle click, B4 'e', B5 'f'
    if (pressedEdge(0)) { toggleAutoMode(AUTO_LCLICK); }
    if (pressedEdge(1)) { toggleAutoMode(AUTO_RCLICK); }
    if (pressedEdge(2)) { toggleAutoMode(AUTO_MCLICK); }
    if (pressedEdge(3)) { toggleAutoMode(AUTO_KEY_E);  }
    if (pressedEdge(4)) { toggleAutoMode(AUTO_KEY_F);  }
  }
}

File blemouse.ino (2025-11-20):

#include <BleMouse.h>
#include <Adafruit_MPU6050.h>
#include <Adafruit_Sensor.h>
#include <Wire.h>

// BLE Mouse
BleMouse bleMouse("ESP32 IMU Mouse", "ESP32", 100);

// Touch sensor pins for mouse buttons
const uint8_t touchPins[] = {12, 14, 27, 33, 32};
const int thresholds[] = {90, 90, 90, 90, 90};
bool buttonStates[] = {false, false, false, false, false};

// Mode toggle pin
const int modeTogglePin = 26; // Using digital pin 26 for mode toggle
bool lastToggleState = false;

// MPU6050
Adafruit_MPU6050 mpu;
#define BUFFER_SIZE 5  // Smaller buffer for more responsive mouse

// Arrays to store last N readings for averaging
float accelXBuffer[BUFFER_SIZE] = {0};
float accelYBuffer[BUFFER_SIZE] = {0};
float accelZBuffer[BUFFER_SIZE] = {0};
float gyroXBuffer[BUFFER_SIZE] = {0};
float gyroYBuffer[BUFFER_SIZE] = {0};
float gyroZBuffer[BUFFER_SIZE] = {0};
int currentIndex = 0;

// Mouse control variables
bool relativeMode = true; // Start with relative mode (traditional mouse)
int mouseSensitivity = 1; // Adjust this to change mouse speed
unsigned long lastMouseUpdate = 0;
const long mouseInterval = 15; // Update mouse every 15ms for responsiveness

void calculateAverages(float &avgAccelX, float &avgAccelY, float &avgAccelZ, 
                      float &avgGyroX, float &avgGyroY, float &avgGyroZ) {
    float sumAccelX = 0, sumAccelY = 0, sumAccelZ = 0;
    float sumGyroX = 0, sumGyroY = 0, sumGyroZ = 0;

    for (int i = 0; i < BUFFER_SIZE; i++) {
        sumAccelX += accelXBuffer[i];
        sumAccelY += accelYBuffer[i];
        sumAccelZ += accelZBuffer[i];
        sumGyroX += gyroXBuffer[i];
        sumGyroY += gyroYBuffer[i];
        sumGyroZ += gyroZBuffer[i];
    }

    avgAccelX = sumAccelX / BUFFER_SIZE;
    avgAccelY = sumAccelY / BUFFER_SIZE;
    avgAccelZ = sumAccelZ / BUFFER_SIZE;
    avgGyroX = sumGyroX / BUFFER_SIZE;
    avgGyroY = sumGyroY / BUFFER_SIZE;
    avgGyroZ = sumGyroZ / BUFFER_SIZE;
}

void updateMPUBuffer() {
    sensors_event_t a, g, temp;
    mpu.getEvent(&a, &g, &temp);

    accelXBuffer[currentIndex] = a.acceleration.x;
    accelYBuffer[currentIndex] = a.acceleration.y;
    accelZBuffer[currentIndex] = a.acceleration.z;
    gyroXBuffer[currentIndex] = g.gyro.x;
    gyroYBuffer[currentIndex] = g.gyro.y;
    gyroZBuffer[currentIndex] = g.gyro.z;

    currentIndex = (currentIndex + 1) % BUFFER_SIZE;
}

void handleMouseButtons() {
    for (int i = 0; i < 5; i++) {
        int touchValue = touchRead(touchPins[i]);
        bool isTouched = touchValue < thresholds[i];

        if (isTouched && !buttonStates[i]) {
            buttonStates[i] = true;
            Serial.print("Button ");
            Serial.print(i);
            Serial.println(" PRESSED");
            
            if (i == 0) {
                bleMouse.press(MOUSE_LEFT);
            } else if (i == 1) {
                bleMouse.press(MOUSE_RIGHT);
            } else if (i == 2) {
                bleMouse.press(MOUSE_MIDDLE);
            } else if (i == 3) {
                bleMouse.press(MOUSE_BACK);
            } else if (i == 4) {
                bleMouse.press(MOUSE_FORWARD);
            }
        } else if (!isTouched && buttonStates[i]) {
            buttonStates[i] = false;
            Serial.print("Button ");
            Serial.print(i);
            Serial.println(" RELEASED");
            
            if (i == 0) {
                bleMouse.release(MOUSE_LEFT);
            } else if (i == 1) {
                bleMouse.release(MOUSE_RIGHT);
            } else if (i == 2) {
                bleMouse.release(MOUSE_MIDDLE);
            } else if (i == 3) {
                bleMouse.release(MOUSE_BACK);
            } else if (i == 4) {
                bleMouse.release(MOUSE_FORWARD);
            }
        }
    }
}

void handleMouseMovement() {
    if (millis() - lastMouseUpdate < mouseInterval) return;
    lastMouseUpdate = millis();
    
    float avgAccelX, avgAccelY, avgAccelZ, avgGyroX, avgGyroY, avgGyroZ;
    calculateAverages(avgAccelX, avgAccelY, avgAccelZ, avgGyroX, avgGyroY, avgGyroZ);
    
    if (relativeMode) {
        // Relative mode: Use gyro for mouse movement (like a traditional mouse)
        int deltaX = (int)(avgGyroY * 150 * mouseSensitivity);
        int deltaY = (int)(avgGyroX * 150 * mouseSensitivity);
        
        // Apply dead zone and constraints
        if (abs(deltaX) > 3 || abs(deltaY) > 3) {
            // Limit maximum movement to prevent jumping
            deltaX = constrain(deltaX, -30, 30);
            deltaY = constrain(deltaY, -30, 30);
            bleMouse.move(deltaX, deltaY);
        }
    } else {
        // Absolute mode: Use accelerometer for pointing
        // Map tilt to cursor movement
        int absX = (int)(avgAccelY * 20 * mouseSensitivity);
        int absY = (int)(avgAccelX * 20 * mouseSensitivity);
        
        // Constrain movement
        absX = constrain(absX, -30, 30);
        absY = constrain(absY, -30, 30);
        
        bleMouse.move(absX, absY);
    }
}

void handleModeToggle() {
    bool currentToggleState = digitalRead(modeTogglePin) == LOW; // Assuming pull-up, so LOW means pressed
    
    if (currentToggleState && !lastToggleState) {
        relativeMode = !relativeMode;
        Serial.print("Switched to ");
        Serial.println(relativeMode ? "RELATIVE mode" : "ABSOLUTE mode");
        delay(300); // Debounce
    }
    lastToggleState = currentToggleState;
}

void setup() {
    Serial.begin(115200);
    
    // Initialize BLE Mouse
    bleMouse.begin();
    
    // Initialize MPU6050
    if (!mpu.begin()) {
        Serial.println("Failed to find MPU6050 chip");
        while (1) delay(10);
    }
    
    // Set up MPU6050 for mouse control
    mpu.setAccelerometerRange(MPU6050_RANGE_4_G);
    mpu.setGyroRange(MPU6050_RANGE_500_DEG);
    mpu.setFilterBandwidth(MPU6050_BAND_21_HZ);
    Serial.println("MPU6050 initialized!");

    // Setup mode toggle pin
    pinMode(modeTogglePin, INPUT_PULLUP);

    // Initialize MPU buffer
    for (int i = 0; i < BUFFER_SIZE; i++) {
        updateMPUBuffer();
        delay(10);
    }
    
    Serial.println("ESP32 IMU Mouse Ready!");
    Serial.println("Touch Pins: 12=Left, 14=Right, 27=Middle, 33=Back, 32=Forward");
    Serial.println("Digital Pin 26: Toggle Relative/Absolute Mode");
    Serial.println("Waiting for BLE connection...");
}

void loop() {
    if (bleMouse.isConnected()) {
        updateMPUBuffer(); // Keep updating IMU data
        handleMouseButtons();
        handleModeToggle();
        handleMouseMovement();
    } else {
        // Reset button states when disconnected
        for (int i = 0; i < 5; i++) {
            buttonStates[i] = false;
        }
        Serial.println("Waiting for BLE connection...");
        delay(1000);
    }
    
    delay(10);
}

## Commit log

2025-09-10 Backup local KiCad projects into repo
    [Attachment2.csv, Attachment2.kicad_pcb, Attachment2.kicad_sch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]
2025-09-10 Backup all KiCad projects into repo/KiCad folder
    [Attachment2.csv, Attachment2.kicad_pcb, Attachment2.kicad_sch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]
2025-09-15 9-15-25 test upload from puter
    [Attachment2.csv, IntegratorTesting.kicad_pcb, IntegratorTesting.kicad_sch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]
2025-11-20 Implement BLE mouse with MPU6050 and touch sensors
    This code implements a BLE mouse using an ESP32 and MPU6050 sensor. It includes touch sensor handling for mouse buttons and toggles between relative and absolute mouse modes.
2026-02-16 Add reference images to README
    Added reference images for PCB layout, attachment, and finished build.
